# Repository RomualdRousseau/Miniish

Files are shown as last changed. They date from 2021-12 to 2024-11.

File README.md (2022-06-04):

# Miniish - Homebrew 6502 Computer

The goal of this project is to build a 8bit game console based on 6502 CPU.
The entire project is strongly inspired by the work and videos of Ben Eater, but
also Javidx9 and his emulator.

## Mother Board

It is basically the same hardware design presented by Ben Eater. I just cleaned
up the adress control logic to have as mush of the 32K RAM available.

The address plan is:

0000 --------------------------------

//   RAM

8000 --------------------------------

//   LO ROM

D000 --------------------------------

//   IRQ Status

D100 --------------------------------

//   PICTURE PROCESSING UNIT (PORT1B)

D200 --------------------------------

//   AUDIO PROCESSING UNIT (PORT2B)

D300 --------------------------------

//   I/O

D400 --------------------------------

//   Reserved

E000 --------------------------------

//   HI ROM

FFFF --------------------------------

## Picture Processing Unit (PPU)

### VGA Card

The card is built using a FPGA and strongly inspired to the NES PPU and the
capability of PICO-8.

The overall specs of the VGA card is 16 colors with a 128x128 display area using
the VGA 640x480 60Hz standard. The 16 colors are the PICO8 palette.

The VGA card is interfaced to the motherboard through a sprite based unit. The
video ram is not mapped to the computer ram but instead, the CPU sends instructions
to a sprite generator very similar to the NES (greatly based on Javidx9
explanations).

The overall spec of the sprite generator is:

* 1 nametables for the background composed of 16 * 16 tiles. Each tile is 8x8
pixels. Scrolling vertical and horizontal modes are supported.

* 256 sprites with tansparency support. Each sprite is also a tile of 8x8 pixels.

* 64 simultaneous sprites on screen and 16 sprites per scanline

* NMI is generated at each vertical blank

## Audio Procesing Unit (APU)

The card is built using a ATMEGA328p at 20Mhz with the library the_synth of Edgar.

The synthetizer has the overall spec: 

* 4 channels at 20KHz

* 4 waveforms: triangle, square, sinus + noise

* 4 envelopes

* modulation

* IRQ0 is generated as the next data frame callback

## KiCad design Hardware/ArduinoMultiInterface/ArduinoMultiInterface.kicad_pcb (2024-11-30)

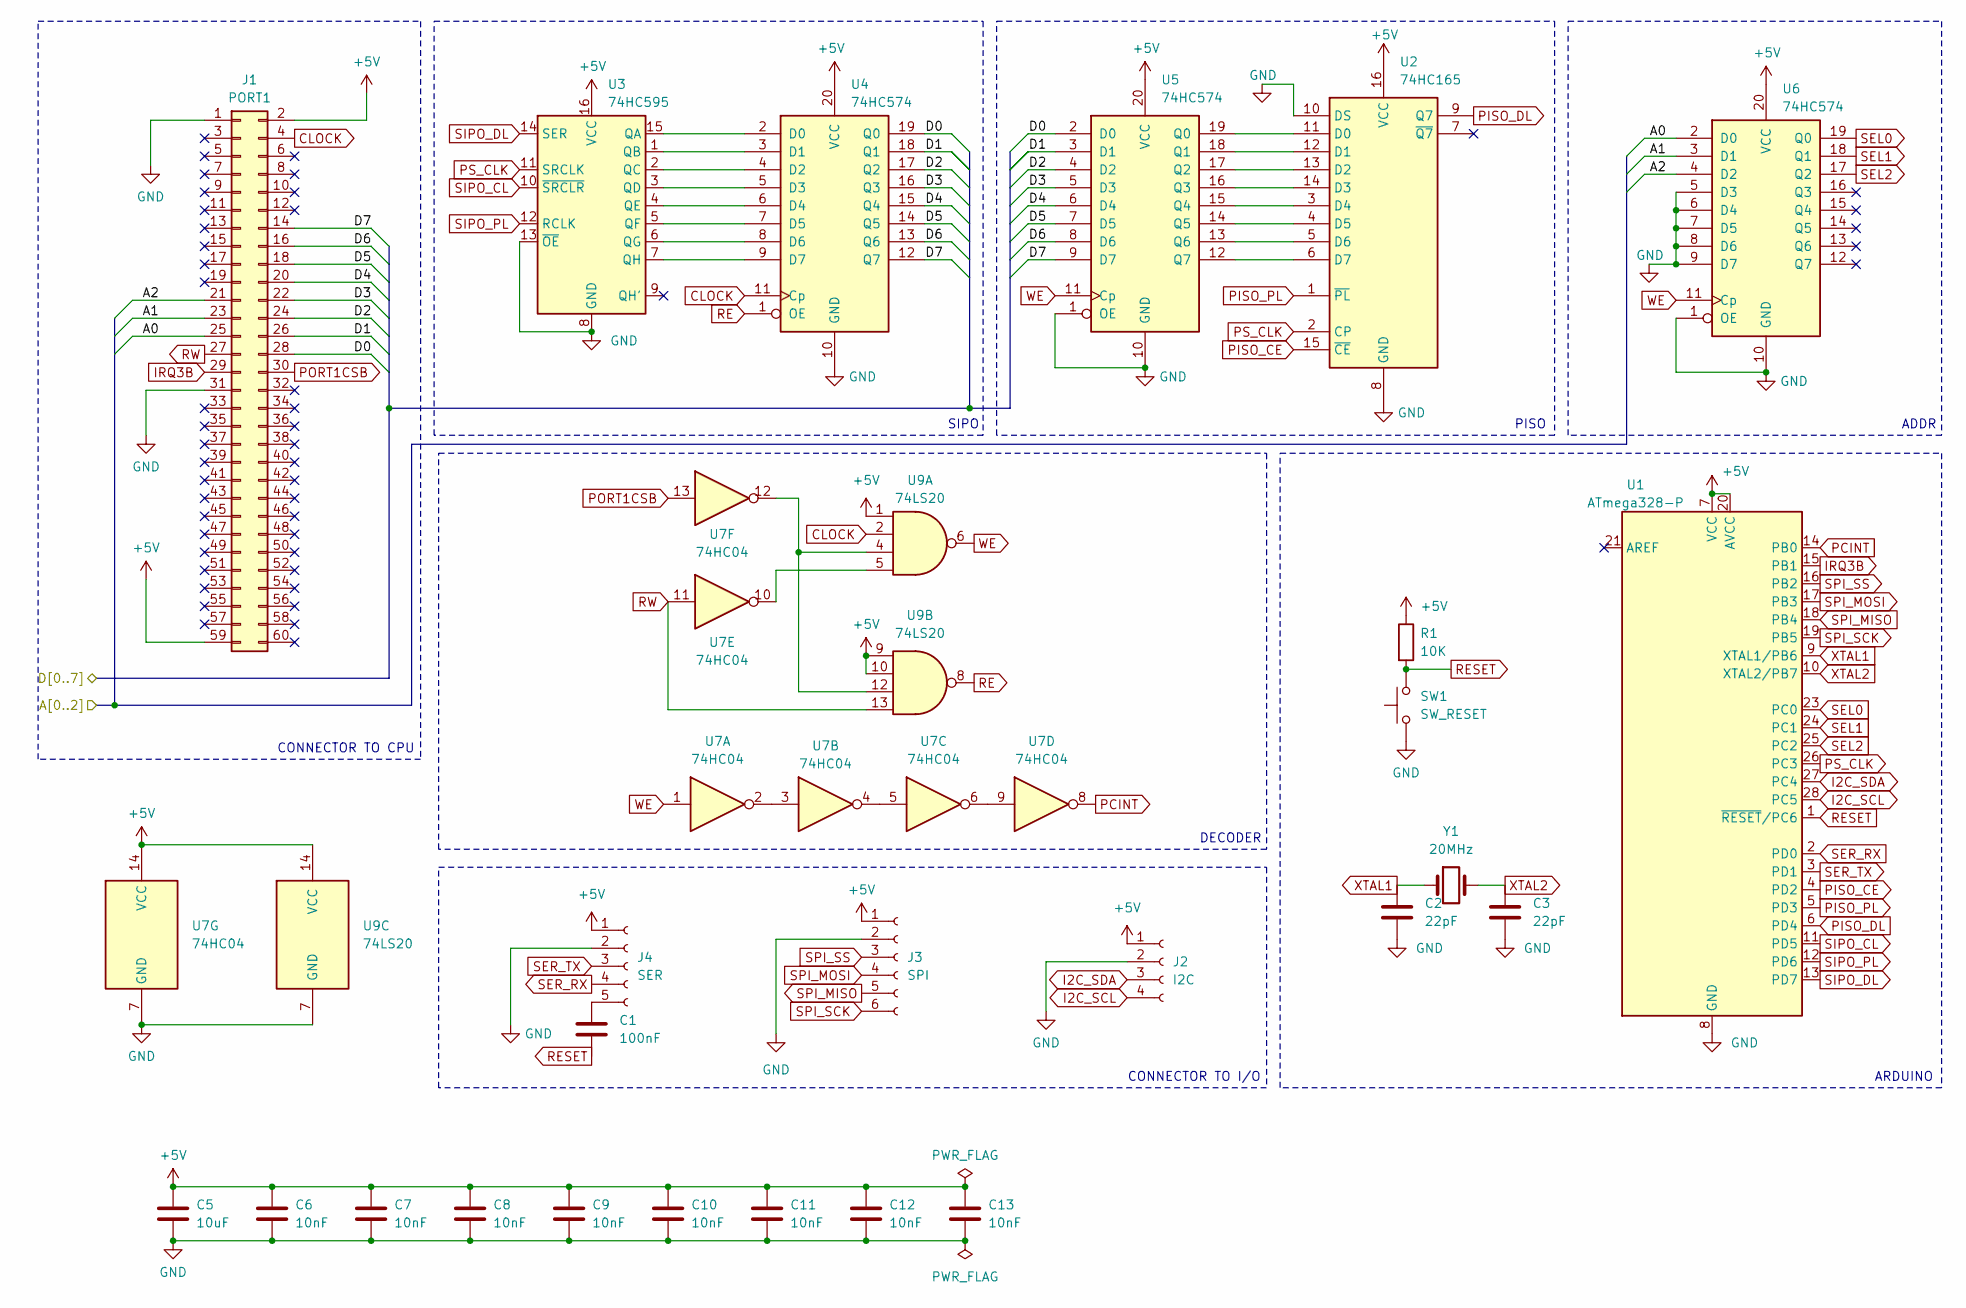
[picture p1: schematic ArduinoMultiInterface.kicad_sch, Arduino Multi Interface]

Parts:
C1: 100nF; C_Disc_D5.0mm_W2.5mm_P2.50mm
C2, C3: 22pF; C_Disc_D5.0mm_W2.5mm_P2.50mm
C5: 10uF; CP_Radial_D5.0mm_P2.00mm
C6, C7, C8, C9, C10, C11, C12, C13: 10nF; C_Disc_D5.0mm_W2.5mm_P5.00mm
J1: PORT1; NES_PCBEdge
J2: I2C; PinSocket_1x04_P2.54mm_Vertical
J3: SPI; PinSocket_1x06_P2.54mm_Vertical
J4: SER; PinSocket_1x05_P2.54mm_Vertical
R1: 10K; R_Axial_DIN0207_L6.3mm_D2.5mm_P10.16mm_Horizontal
SW1: SW_RESET; SW_PUSH_6mm
U1: ATmega328-P; DIP-28_W7.62mm
U2: 74HC165; DIP-16_W7.62mm
U3: 74HC595; DIP-16_W7.62mm
U4, U5, U6: 74HC574; DIP-20_W7.62mm
U7: 74HC04; DIP-14_W7.62mm
U9: 74LS20; DIP-14_W7.62mm
Y1: 20MHz; Crystal_HC49-4H_Vertical

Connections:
+5V: C5.1, C6.1, C7.1, C8.1, C9.1, C10.1, C11.1, C12.1, C13.1, J1.2, J1.59, J2.1, J3.1, J4.1, R1.1, U1.7 (VCC), U1.20 (AVCC), U2.16 (VCC), U3.16 (VCC), U4.20 (VCC), U5.20 (VCC), U6.20 (VCC), U7.14 (VCC), U9.1, U9.9, U9.10, U9.14 (VCC)
/A0: J1.25, U6.2 (D0)
/A1: J1.23, U6.3 (D1)
/A2: J1.21, U6.4 (D2)
/D0: J1.28, U4.19 (Q0), U5.2 (D0)
/D1: J1.26, U4.18 (Q1), U5.3 (D1)
/D2: J1.24, U4.17 (Q2), U5.4 (D2)
/D3: J1.22, U4.16 (Q3), U5.5 (D3)
/D4: J1.20, U4.15 (Q4), U5.6 (D4)
/D5: J1.18, U4.14 (Q5), U5.7 (D5)
/D6: J1.16, U4.13 (Q6), U5.8 (D6)
/D7: J1.14, U4.12 (Q7), U5.9 (D7)
CLOCK: J1.4, U4.11 (Cp), U9.2
GND: C2.2, C3.2, C5.2, C6.2, C7.2, C8.2, C9.2, C10.2, C11.2, C12.2, C13.2, J1.1, J1.31, J2.2, J3.2, J4.2, SW1.1, U1.8 (GND), U1.22 (GND), U2.8 (GND), U2.10 (DS), U3.8 (GND), U3.13 (~OE), U4.10 (GND), U5.1 (OE), U5.10 (GND), U6.1 (OE), U6.5 (D3), U6.6 (D4), U6.7 (D5), U6.8 (D6), U6.9 (D7), U6.10 (GND), U7.7 (GND), U9.7 (GND)
I2C_SCL: J2.4, U1.28 (PC5)
I2C_SDA: J2.3, U1.27 (PC4)
IRQ3B: J1.29, U1.15 (PB1)
unnamed: C1.1, J4.5
unnamed: U2.11 (D0), U5.19 (Q0)
unnamed: U2.12 (D1), U5.18 (Q1)
unnamed: U2.13 (D2), U5.17 (Q2)
unnamed: U2.14 (D3), U5.16 (Q3)
unnamed: U2.3 (D4), U5.15 (Q4)
unnamed: U2.4 (D5), U5.14 (Q5)
unnamed: U2.5 (D6), U5.13 (Q6)
unnamed: U2.6 (D7), U5.12 (Q7)
unnamed: U3.15 (QA), U4.2 (D0)
unnamed: U3.1 (QB), U4.3 (D1)
unnamed: U3.2 (QC), U4.4 (D2)
unnamed: U3.3 (QD), U4.5 (D3)
unnamed: U3.4 (QE), U4.6 (D4)
unnamed: U3.5 (QF), U4.7 (D5)
unnamed: U3.6 (QG), U4.8 (D6)
unnamed: U3.7 (QH), U4.9 (D7)
unnamed: U7.2, U7.3
unnamed: U7.4, U7.5
unnamed: U7.6, U7.9
unnamed: U7.10, U9.5
unnamed: U7.12, U9.4, U9.12
PCINT: U1.14 (PB0), U7.8
PISO_CE: U1.4 (PD2), U2.15 (~CE)
PISO_DL: U1.6 (PD4), U2.9 (Q7)
PISO_PL: U1.5 (PD3), U2.1 (~PL)
PORT1CSB: J1.30, U7.13
PS_CLK: U1.26 (PC3), U2.2 (CP), U3.11 (SRCLK)
RE: U4.1 (OE), U9.8
RESET: C1.2, R1.2, SW1.2, U1.1 (~RESET/PC6)
RW: J1.27, U7.11, U9.13
SEL0: U1.23 (PC0), U6.19 (Q0)
SEL1: U1.24 (PC1), U6.18 (Q1)
SEL2: U1.25 (PC2), U6.17 (Q2)
SER_RX: J4.4, U1.2 (PD0)
SER_TX: J4.3, U1.3 (PD1)
SIPO_CL: U1.11 (PD5), U3.10 (~SRCLR)
SIPO_DL: U1.13 (PD7), U3.14 (SER)
SIPO_PL: U1.12 (PD6), U3.12 (RCLK)
SPI_MISO: J3.5, U1.18 (PB4)
SPI_MOSI: J3.4, U1.17 (PB3)
SPI_SCK: J3.6, U1.19 (PB5)
SPI_SS: J3.3, U1.16 (PB2)
WE: U5.11 (Cp), U6.11 (Cp), U7.1, U9.6
XTAL1: C2.1, U1.9 (XTAL1/PB6), Y1.1
XTAL2: C3.1, U1.10 (XTAL2/PB7), Y1.2

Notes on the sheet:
CONNECTOR TO CPU
ARDUINO
PISO
DECODER
SIPO
ADDR
CONNECTOR TO I/O

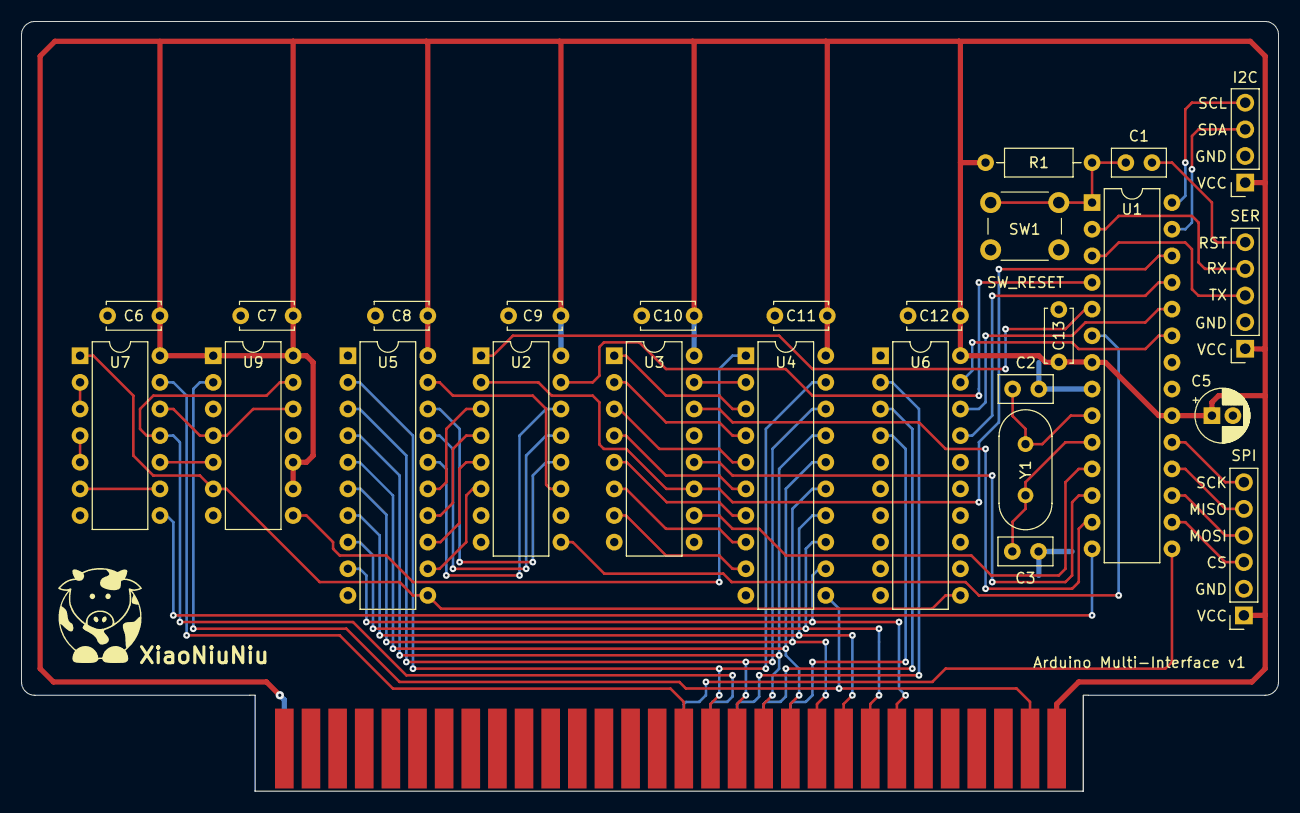
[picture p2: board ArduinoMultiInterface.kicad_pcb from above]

Board: 2 copper layers, 119.9 x 73.4 mm, 28 parts (0 on the bottom side), 63 nets.

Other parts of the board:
XiaoNiuNiu: LOGO; VerySmallCow

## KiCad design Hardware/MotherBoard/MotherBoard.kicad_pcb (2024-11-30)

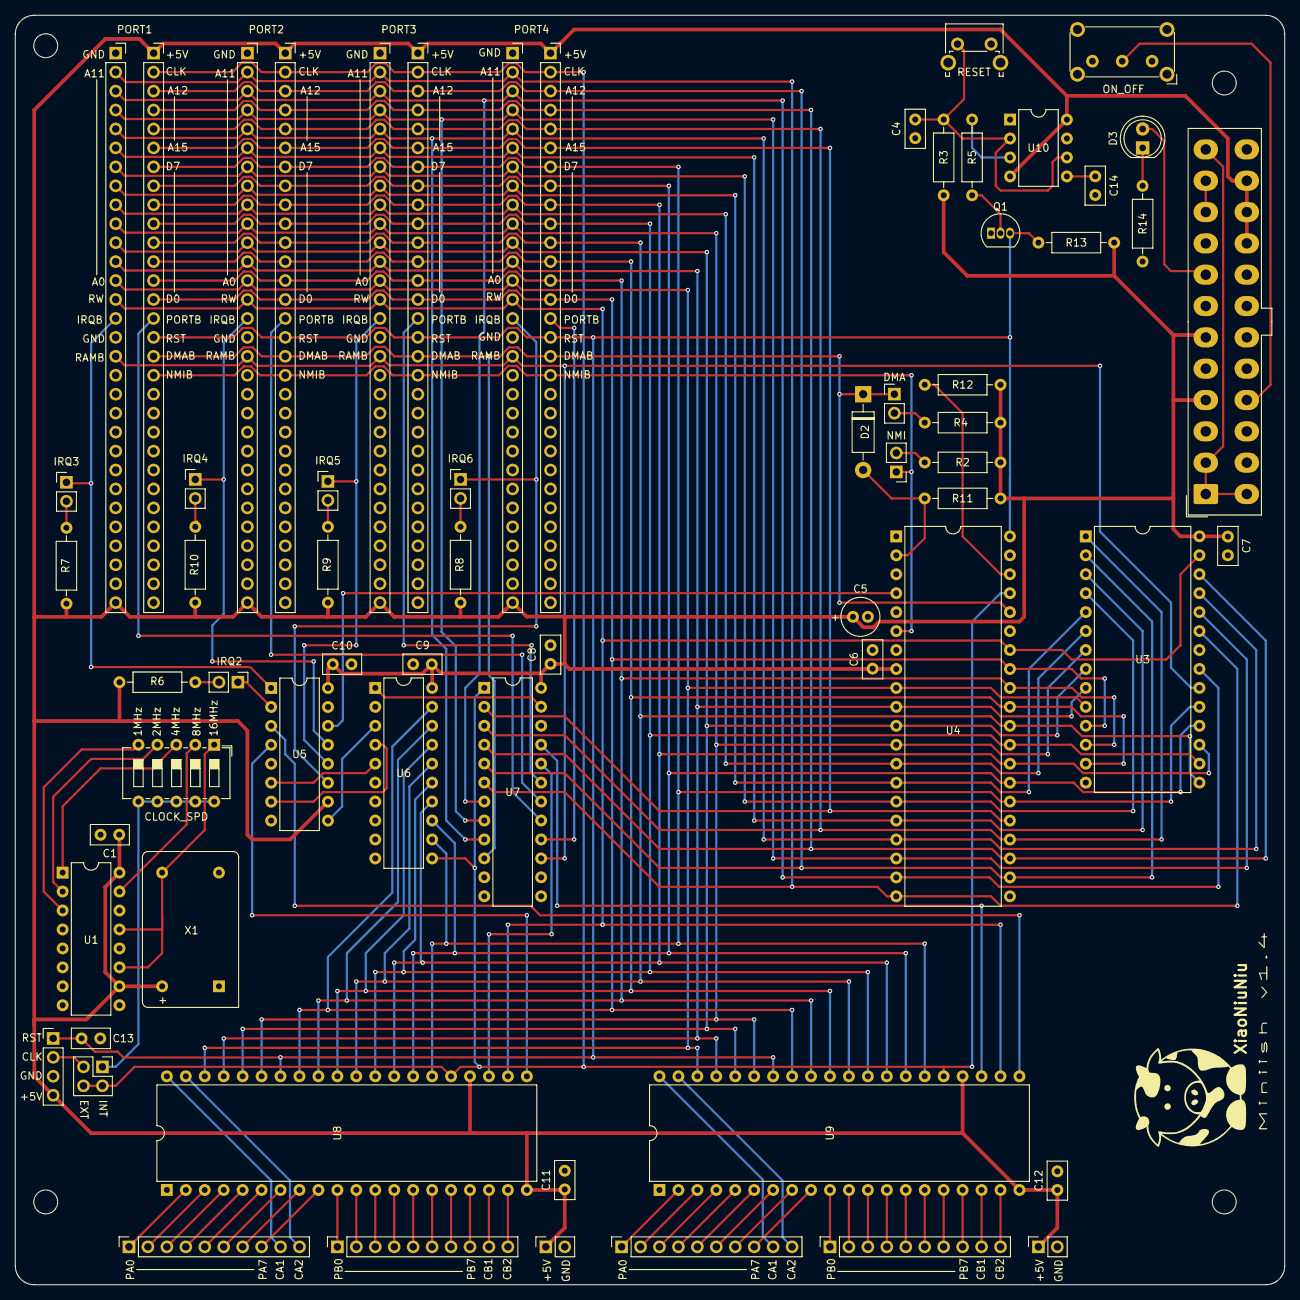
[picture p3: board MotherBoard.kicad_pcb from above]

Board: 2 copper layers, 170.2 x 170.2 mm, 66 parts (0 on the bottom side), 113 nets.

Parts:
C1, C4, C6, C7, C9, C10, C11, C12, C13: 100nF; C_Disc_D5.0mm_W2.5mm_P2.50mm
C5: 10uF; C_Radial_D5.0mm_H11.0mm_P2.00mm
C8: 220nF; C_Disc_D5.0mm_W2.5mm_P2.50mm
C14: 10nF; C_Disc_D5.0mm_W2.5mm_P2.50mm
D2: 1N4001; D_DO-41_SOD81_P10.16mm_Horizontal
D3: LED; LED_D5.0mm
H1, H2, H3, H4: MountingHole_Pad; MountingHole_3.2mm_M3
J3: CLOCK_SEL; PinHeader_2x02_P2.54mm_Vertical
J4: EXTRN_CLCK; PinHeader_1x04_P2.54mm_Vertical
J5: NMI; PinHeader_1x02_P2.54mm_Vertical
J6: DMA; PinHeader_1x02_P2.54mm_Vertical
J7: IRQ2; PinHeader_1x02_P2.54mm_Vertical
J8: IRQ3; PinHeader_1x02_P2.54mm_Vertical
J9: IRQ6; PinHeader_1x02_P2.54mm_Vertical
J10: IRQ5; PinHeader_1x02_P2.54mm_Vertical
J11: IRQ4; PinHeader_1x02_P2.54mm_Vertical
J14: PORT1; NES_Cartdrige
J16: PORT2; NES_Cartdrige
J17: PORT3; NES_Cartdrige
J18: PORT4/ROM; NES_Cartdrige
J19: GPIO1; PinSocket_1x10_P2.54mm_Vertical
J20: GPIO2; PinSocket_1x10_P2.54mm_Vertical
J21: GPIO1_PWR; PinSocket_1x02_P2.54mm_Vertical
J22: GPIO3; PinSocket_1x10_P2.54mm_Vertical
J23: GPIO4; PinSocket_1x10_P2.54mm_Vertical
J24: GPIO2_PWR; PinSocket_1x02_P2.54mm_Vertical
J25: ATX-24; Molex_Mini-Fit_Jr_5566-24A_2x12_P4.20mm_Vertical
Q1: 2N3904; TO-92_Inline
R2, R4, R6, R7, R8, R9, R10, R11, R12: 3K3; R_Axial_DIN0207_L6.3mm_D2.5mm_P10.16mm_Horizontal
R3: 1M; R_Axial_DIN0207_L6.3mm_D2.5mm_P10.16mm_Horizontal
R5: 4.7K; R_Axial_DIN0207_L6.3mm_D2.5mm_P10.16mm_Horizontal
R13: 10K; R_Axial_DIN0207_L6.3mm_D2.5mm_P10.16mm_Horizontal
R14: 220; R_Axial_DIN0207_L6.3mm_D2.5mm_P10.16mm_Horizontal
SW1: CLOCK_SPD; SW_DIP_SPSTx05_Slide_6.7x14.26mm_W7.62mm_P2.54mm_LowProfile
SW2: ON_OFF; SW_E-Switch_EG1224_SPDT_Angled
SW3: RESET; SW_Tactile_SPST_Angled_PTS645Vx83-2LFS
U1: 74HC590A; DIP-16_W7.62mm
U3: AS6C62256; DIP-28_W15.24mm
U4: WD65C02; DIP-40_W15.24mm
U5: 74HC148; DIP-16_W7.62mm
U6: 74HC574; DIP-20_W7.62mm
U7: ATF22V10B; DIP-24_W7.62mm
U8, U9: WD65C22; DIP-40_W15.24mm
U10: NE555P; DIP-8_W7.62mm
X1: ACO-16MHz; Oscillator_DIP-14
XiaoNiuNiu: LOGO; SmallCow

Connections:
+5V: C1.1, C5.1, C6.1, C7.1, C8.1, C9.1, C10.1, C11.1, C12.1, J4.4, J14.2, J14.59, J16.2, J16.59, J17.2, J17.59, J18.2, J18.59, J21.1, J24.1, J25.4 (+5V), J25.6 (+5V), J25.21 (+5V), J25.22 (+5V), J25.23 (+5V), R2.2, R3.1, R4.2, R6.2, R7.2, R8.2, R9.2, R10.2, R11.2, R12.2, R13.2, U1.10 (~MRC), U1.16 (VCC), U3.28 (VCC), U4.8 (VCC), U5.10 (IO), U5.16 (VCC), U6.20 (VCC), U7.24 (VCC), U8.20 (VCC), U8.24 (CS1), U9.20 (VCC), U9.24 (CS1), U10.4 (R), U10.8 (VCC), X1.14 (Vcc)
/1MHz: SW1.5, U1.3 (Q3)
/2MHz: SW1.4, U1.2 (Q2)
/4MHz: SW1.3, U1.1 (Q1)
/8MHz: SW1.2, U1.15 (Q0)
/16MHz: SW1.1, U1.11 (CPC), U1.13 (CPR), X1.8 (OUT)
/GPIO/A0: J14.25, J16.25, J17.25, J18.25, U3.10 (A0), U4.9 (A0), U8.38 (RS0), U9.38 (RS0)
/GPIO/A1: J14.23, J16.23, J17.23, J18.23, U3.9 (A1), U4.10 (A1), U8.37 (RS1), U9.37 (RS1)
/GPIO/A2: J14.21, J16.21, J17.21, J18.21, U3.8 (A2), U4.11 (A2), U8.36 (RS2), U9.36 (RS2)
/GPIO/A3: J14.19, J16.19, J17.19, J18.19, U3.7 (A3), U4.12 (A3), U8.35 (RS3), U9.35 (RS3)
/GPIO/A4: J14.17, J16.17, J17.17, J18.17, U3.6 (A4), U4.13 (A4)
/GPIO/A5: J14.15, J16.15, J17.15, J18.15, U3.5 (A5), U4.14 (A5)
/GPIO/A6: J14.13, J16.13, J17.13, J18.13, U3.4 (A6), U4.15 (A6)
/GPIO/A7: J14.11, J16.11, J17.11, J18.11, U3.3 (A7), U4.16 (A7)
/GPIO/A8: J14.9, J16.9, J17.9, J18.9, U3.25 (A8), U4.17 (A8), U7.9 (I7)
/GPIO/A9: J14.7, J16.7, J17.7, J18.7, U3.24 (A9), U4.18 (A9), U7.8 (I6)
/GPIO/A10: J14.5, J16.5, J17.5, J18.5, U3.21 (A10), U4.19 (A10), U7.7 (I5)
/GPIO/A11: J14.3, J16.3, J17.3, J18.3, U3.23 (A11), U4.20 (A11), U7.6 (I4)
/GPIO/A12: J14.6, J16.6, J17.6, J18.6, U3.2 (A12), U4.22 (A12), U7.5 (I3)
/GPIO/A13: J14.8, J16.8, J17.8, J18.8, U3.26 (A13), U4.23 (A13), U7.4 (I2)
/GPIO/A14: J14.10, J16.10, J17.10, J18.10, U3.1 (A14), U4.24 (A14), U7.3 (I1)
/GPIO/A15: J14.12, J16.12, J17.12, J18.12, U4.25 (A15), U7.2 (I0)
/GPIO/CIA1CSB: U7.20 (O3), U8.23 (~CS2)
/GPIO/CIA2CSB: U7.21 (O2), U9.23 (~CS2)
/GPIO/D0: J14.28, J16.28, J17.28, J18.28, U3.11 (Q0), U4.33 (D0), U6.19 (Q0), U8.33 (D0), U9.33 (D0)
/GPIO/D1: J14.26, J16.26, J17.26, J18.26, U3.12 (Q1), U4.32 (D1), U6.18 (Q1), U8.32 (D1), U9.32 (D1)
/GPIO/D2: J14.24, J16.24, J17.24, J18.24, U3.13 (Q2), U4.31 (D2), U6.17 (Q2), U8.31 (D2), U9.31 (D2)
/GPIO/D3: J14.22, J16.22, J17.22, J18.22, U3.15 (Q3), U4.30 (D3), U6.16 (Q3), U8.30 (D3), U9.30 (D3)
/GPIO/D4: J14.20, J16.20, J17.20, J18.20, U3.16 (Q4), U4.29 (D4), U6.15 (Q4), U8.29 (D4), U9.29 (D4)
/GPIO/D5: J14.18, J16.18, J17.18, J18.18, U3.17 (Q5), U4.28 (D5), U6.14 (Q5), U8.28 (D5), U9.28 (D5)
/GPIO/D6: J14.16, J16.16, J17.16, J18.16, U3.18 (Q6), U4.27 (D6), U6.13 (Q6), U8.27 (D6), U9.27 (D6)
/GPIO/D7: J14.14, J16.14, J17.14, J18.14, U3.19 (Q7), U4.26 (D7), U6.12 (Q7), U8.26 (D7), U9.26 (D7)
/GPIO/IRQ0B: U5.4 (I7), U8.21 (~IRQ)
/GPIO/IRQ1B: U5.3 (I6), U9.21 (~IRQ)
/GPIO/RW: J14.27, J16.27, J17.27, J18.27, U3.27 (~WE), U4.34 (R/~W), U8.22 (R/~W), U9.22 (R/~W)
/North Bridge/DMAB: D2.1 (K), J6.1, J14.34, J16.34, J17.34, J18.34, U4.36 (BE), U7.10 (I8)
/North Bridge/IRQB: U4.4 (~IRQ), U5.14 (GS)
/North Bridge/NMIB: J5.1, J14.36, J16.36, J17.36, J18.36, U4.6 (~NMI)
/North Bridge/RAMCSB: J14.33, J16.33, J17.33, J18.33, U3.20 (~CS), U7.15 (O8)
/North Bridge/RDY: D2.2 (A), R11.1, U4.2 (RDY)
/North Bridge/SOB: R12.1, U4.38 (~SO)
/Ports/IRQ2B: J7.1, U5.2 (I5)
/Ports/IRQ3B: J8.1, J14.29, U5.1 (I4)
/Ports/IRQ4B: J11.1, J16.29, U5.13 (I3)
/Ports/IRQ5B: J10.1, J17.29, U5.12 (I2)
/Ports/IRQ6B: J9.1, J18.29, U5.11 (I1)
/Ports/PORT1CSB: J14.30, U7.17 (O6)
/Ports/PORT2CSB: J16.30, U7.18 (O5)
/Ports/PORT3CSB: J17.30, U7.19 (O4)
/Ports/ROMCSB: J18.30, U7.16 (O7)
CA11: J19.9, U8.40 (CA1)
CA12: J19.10, U8.39 (CA2)
CA21: J22.9, U9.40 (CA1)
CA22: J22.10, U9.39 (CA2)
CB11: J20.9, U8.18 (CB1)
CB12: J20.10, U8.19 (CB2)
CB21: J23.9, U9.18 (CB1)
CB22: J23.10, U9.19 (CB2)
CLOCK: J3.2, J3.4, J14.4, J16.4, J17.4, J18.4, U4.37 (PHI2), U6.11 (Cp), U7.1 (CLK), U8.25 (PHI2), U9.25 (PHI2)
ECLOCK: J3.3, J4.2
GND: C1.2, C4.2, C5.2, C6.2, C7.2, C8.2, C9.2, C10.2, C11.2, C12.2, C13.2, C14.2, J4.3, J14.1, J14.31, J16.1, J16.31, J17.1, J17.31, J18.1, J18.31, J21.2, J24.2, J25.3 (GND), J25.5 (GND), J25.7 (GND), J25.15 (GND), J25.17 (GND), J25.18 (GND), J25.19 (GND), J25.24 (GND), Q1.1 (E), R14.2, SW2.1 (A), SW3.2, U1.8 (GND), U1.12 (~CE), U1.14 (~OE), U3.14 (GND), U3.22 (~OE), U4.21 (GND), U5.5 (EI), U5.8 (GND), U6.2 (D0), U6.6 (D4), U6.7 (D5), U6.8 (D6), U6.9 (D7), U6.10 (GND), U7.11 (I9), U7.12 (GND), U7.13 (~OE), U8.1 (GND), U9.1 (GND), U10.1 (GND), X1.7 (GND)
unnamed: D3.1 (K), R14.1
unnamed: J3.1, SW1.6, SW1.7, SW1.8, SW1.9, SW1.10
unnamed: J5.2, R2.1
unnamed: J6.2, R4.1
unnamed: J7.2, R6.1
unnamed: J8.2, R7.1
unnamed: J9.2, R8.1
unnamed: J10.2, R9.1
unnamed: J11.2, R10.1
unnamed: J25.16 (PS_ON#), SW2.2 (B)
unnamed: Q1.2 (B), R5.2
unnamed: U5.9 (S0), U6.3 (D1)
unnamed: U5.7 (S1), U6.4 (D2)
unnamed: U5.6 (S2), U6.5 (D3)
unnamed: U6.1 (OE), U7.23 (O0)
unnamed: C14.1, U10.5 (CV)
unnamed: R5.1, U10.3 (Q)
unnamed: C4.1, R3.2, SW3.1, U10.2 (TR), U10.6 (THR)
PA10: J19.1, U8.2 (PA0)
PA11: J19.2, U8.3 (PA1)
PA12: J19.3, U8.4 (PA2)
PA13: J19.4, U8.5 (PA3)
PA14: J19.5, U8.6 (PA4)
PA15: J19.6, U8.7 (PA5)
PA16: J19.7, U8.8 (PA6)
PA17: J19.8, U8.9 (PA7)
PA20: J22.1, U9.2 (PA0)
PA21: J22.2, U9.3 (PA1)
PA22: J22.3, U9.4 (PA2)
PA23: J22.4, U9.5 (PA3)
PA24: J22.5, U9.6 (PA4)
PA25: J22.6, U9.7 (PA5)
PA26: J22.7, U9.8 (PA6)
PA27: J22.8, U9.9 (PA7)
PB10: J20.1, U8.10 (PB0)
PB11: J20.2, U8.11 (PB1)
PB12: J20.3, U8.12 (PB2)
PB13: J20.4, U8.13 (PB3)
PB14: J20.5, U8.14 (PB4)
PB15: J20.6, U8.15 (PB5)
PB16: J20.7, U8.16 (PB6)
PB17: J20.8, U8.17 (PB7)
PB20: J23.1, U9.10 (PB0)
PB21: J23.2, U9.11 (PB1)
PB22: J23.3, U9.12 (PB2)
PB23: J23.4, U9.13 (PB3)
PB24: J23.5, U9.14 (PB4)
PB25: J23.6, U9.15 (PB5)
PB26: J23.7, U9.16 (PB6)
PB27: J23.8, U9.17 (PB7)
PWR_OK: D3.2 (A), J25.8 (PWR_OK)
RESET: C13.1, J4.1, J14.32, J16.32, J17.32, J18.32, Q1.3 (C), R13.1, U4.40 (~RESET), U8.34 (~RESET), U9.34 (~RESET)

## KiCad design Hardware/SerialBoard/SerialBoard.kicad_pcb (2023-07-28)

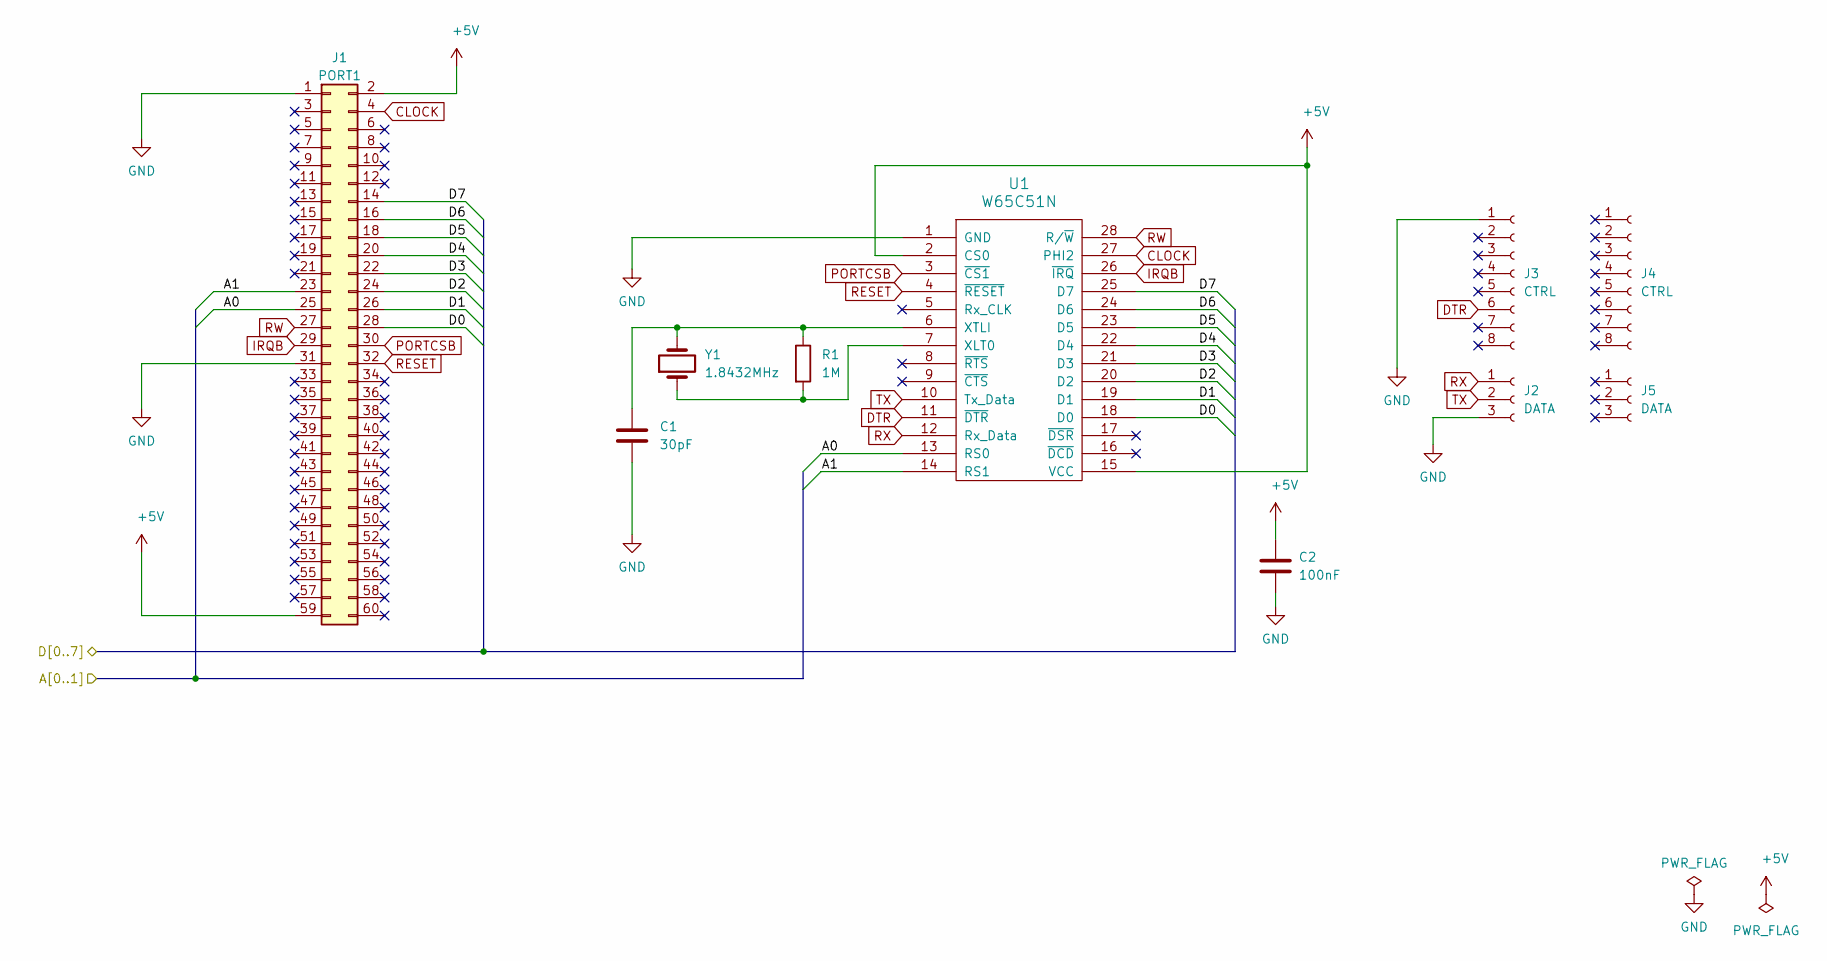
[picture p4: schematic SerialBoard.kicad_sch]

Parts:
C1: 30pF; C_Disc_D5.0mm_W2.5mm_P2.50mm
C2: 100nF; C_Disc_D5.0mm_W2.5mm_P2.50mm
J1: PORT1; NES_PCBEdge
J2, J5: DATA; PinSocket_1x03_P2.54mm_Vertical
J3, J4: CTRL; PinSocket_1x08_P2.54mm_Vertical
R1: 1M; R_Axial_DIN0207_L6.3mm_D2.5mm_P10.16mm_Horizontal
U1: W65C51N; DIP-28_W15.24mm
Y1: 1.8432MHz; Crystal_HC49-4H_Vertical

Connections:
+5V: C2.1, J1.2, J1.59, U1.2 (CS0), U1.15 (VCC)
/A0: J1.25, U1.13 (RS0)
/A1: J1.23, U1.14 (RS1)
/D0: J1.28, U1.18 (D0)
/D1: J1.26, U1.19 (D1)
/D2: J1.24, U1.20 (D2)
/D3: J1.22, U1.21 (D3)
/D4: J1.20, U1.22 (D4)
/D5: J1.18, U1.23 (D5)
/D6: J1.16, U1.24 (D6)
/D7: J1.14, U1.25 (D7)
CLOCK: J1.4, U1.27 (PHI2)
DTR: J3.6, U1.11 (~DTR)
GND: C1.2, C2.2, J1.1, J1.31, J2.3, J3.1, U1.1 (GND)
IRQB: J1.29, U1.26 (~IRQ)
unnamed: R1.2, U1.7 (XLT0), Y1.1
unnamed: C1.1, R1.1, U1.6 (XTLI), Y1.2
PORTCSB: J1.30, U1.3 (~CS1)
RESET: J1.32, U1.4 (~RESET)
RW: J1.27, U1.28 (R/~W)
RX: J2.1, U1.12 (Rx_Data)
TX: J2.2, U1.10 (Tx_Data)

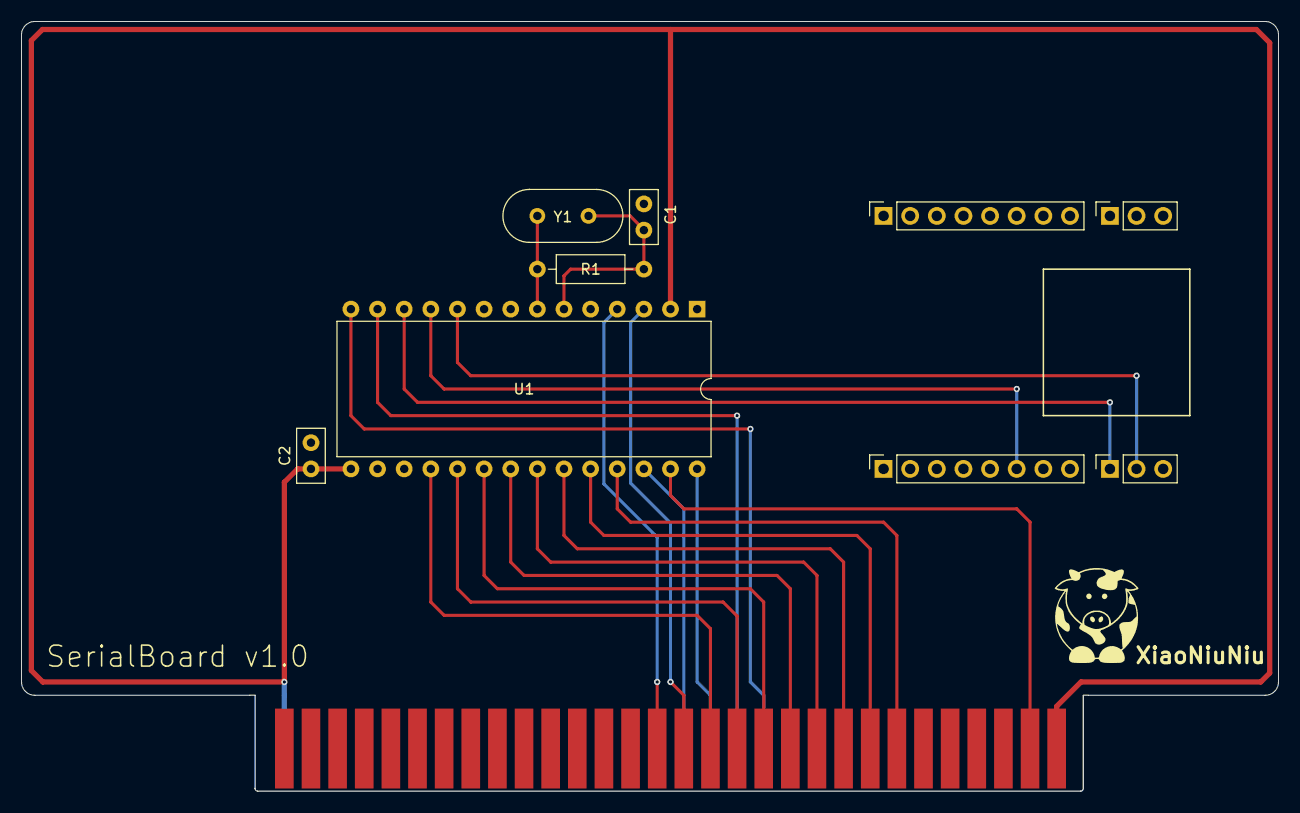
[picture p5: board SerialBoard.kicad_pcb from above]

Board: 2 copper layers, 119.9 x 73.4 mm, 11 parts (0 on the bottom side), 22 nets.

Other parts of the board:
XiaoNiuNiu: LOGO; VerySmallCow

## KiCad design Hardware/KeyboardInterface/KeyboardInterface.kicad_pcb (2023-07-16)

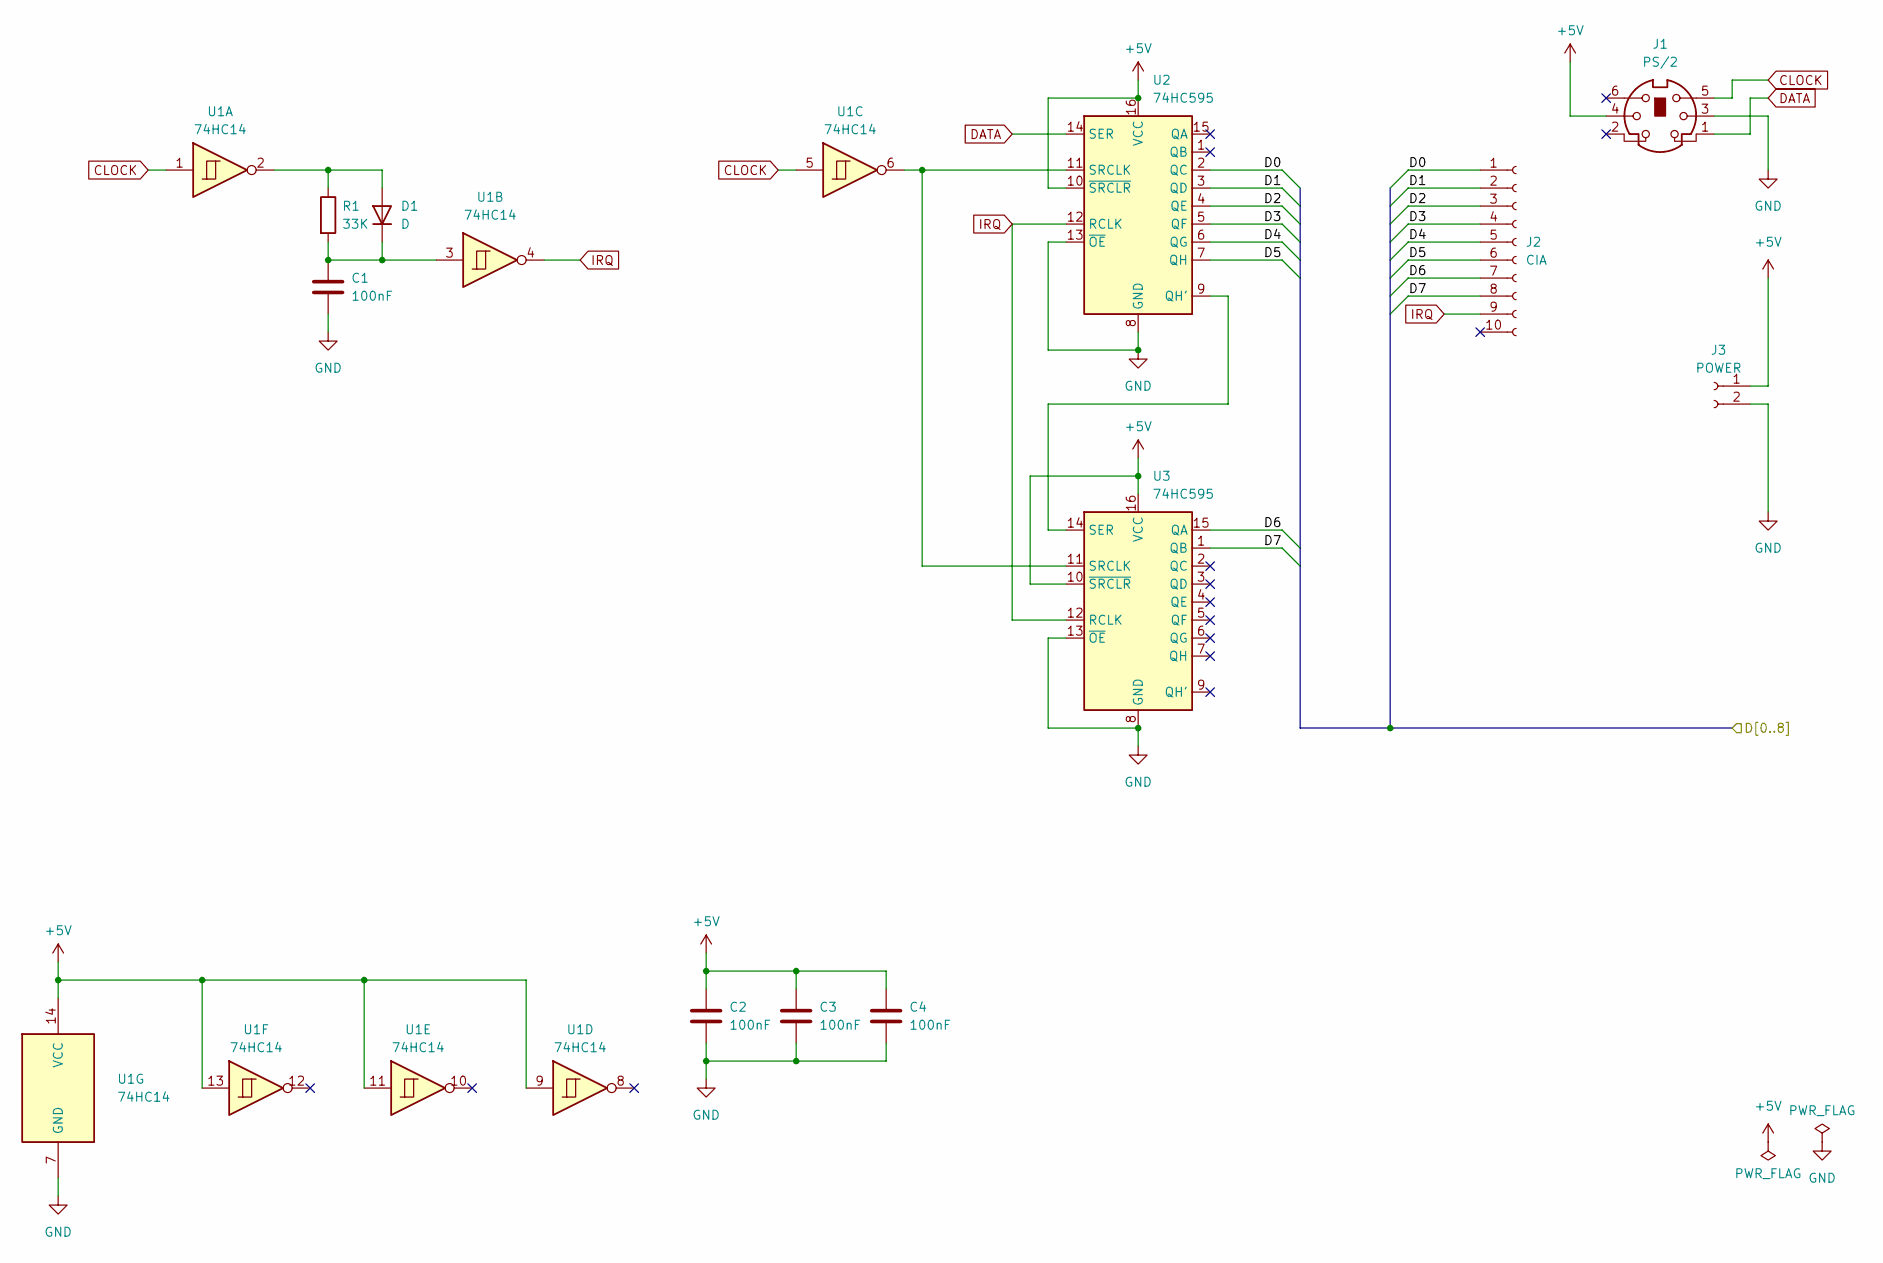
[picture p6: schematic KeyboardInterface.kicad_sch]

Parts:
C1, C2, C3, C4: 100nF; C_Disc_D5.0mm_W2.5mm_P2.50mm
D1: D; D_A-405_P10.16mm_Horizontal
J1: PS/2; Mini_din6
J2: CIA; PinSocket_1x10_P2.54mm_Vertical
J3: POWER; PinSocket_1x02_P2.54mm_Vertical
R1: 33K; R_Axial_DIN0309_L9.0mm_D3.2mm_P12.70mm_Horizontal
U1: 74HC14; DIP-14_W7.62mm
U2, U3: 74HC595; DIP-16_W7.62mm

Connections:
+5V: C2.1, C3.1, C4.1, J1.4, J3.1, U1.9, U1.11, U1.13, U1.14 (VCC), U2.10 (~SRCLR), U2.16 (VCC), U3.10 (~SRCLR), U3.16 (VCC)
/D0: J2.1, U2.2 (QC)
/D1: J2.2, U2.3 (QD)
/D2: J2.3, U2.4 (QE)
/D3: J2.4, U2.5 (QF)
/D4: J2.5, U2.6 (QG)
/D5: J2.6, U2.7 (QH)
/D6: J2.7, U3.15 (QA)
/D7: J2.8, U3.1 (QB)
CLOCK: J1.5, U1.1, U1.5
DATA: J1.1, U2.14 (SER)
GND: C1.2, C2.2, C3.2, C4.2, J1.3, J3.2, U1.7 (GND), U2.8 (GND), U2.13 (~OE), U3.8 (GND), U3.13 (~OE)
IRQ: J2.9, U1.4, U2.12 (RCLK), U3.12 (RCLK)
unnamed: D1.2 (A), R1.1, U1.2
unnamed: C1.1, D1.1 (K), R1.2, U1.3
unnamed: U2.9 (QH'), U3.14 (SER)
unnamed: U1.6, U2.11 (SRCLK), U3.11 (SRCLK)

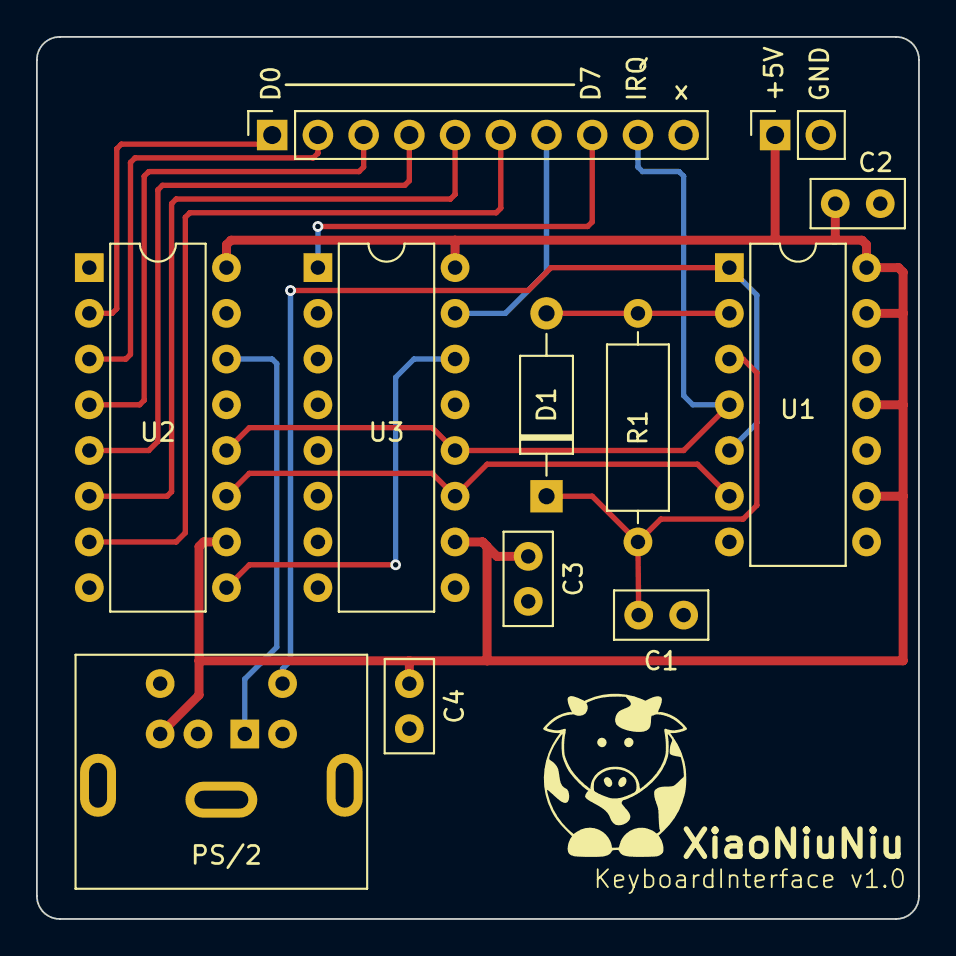
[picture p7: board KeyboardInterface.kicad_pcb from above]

Board: 2 copper layers, 49.0 x 49.0 mm, 13 parts (0 on the bottom side), 17 nets.

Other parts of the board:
XiaoNiuNiu: LOGO; VerySmallCow

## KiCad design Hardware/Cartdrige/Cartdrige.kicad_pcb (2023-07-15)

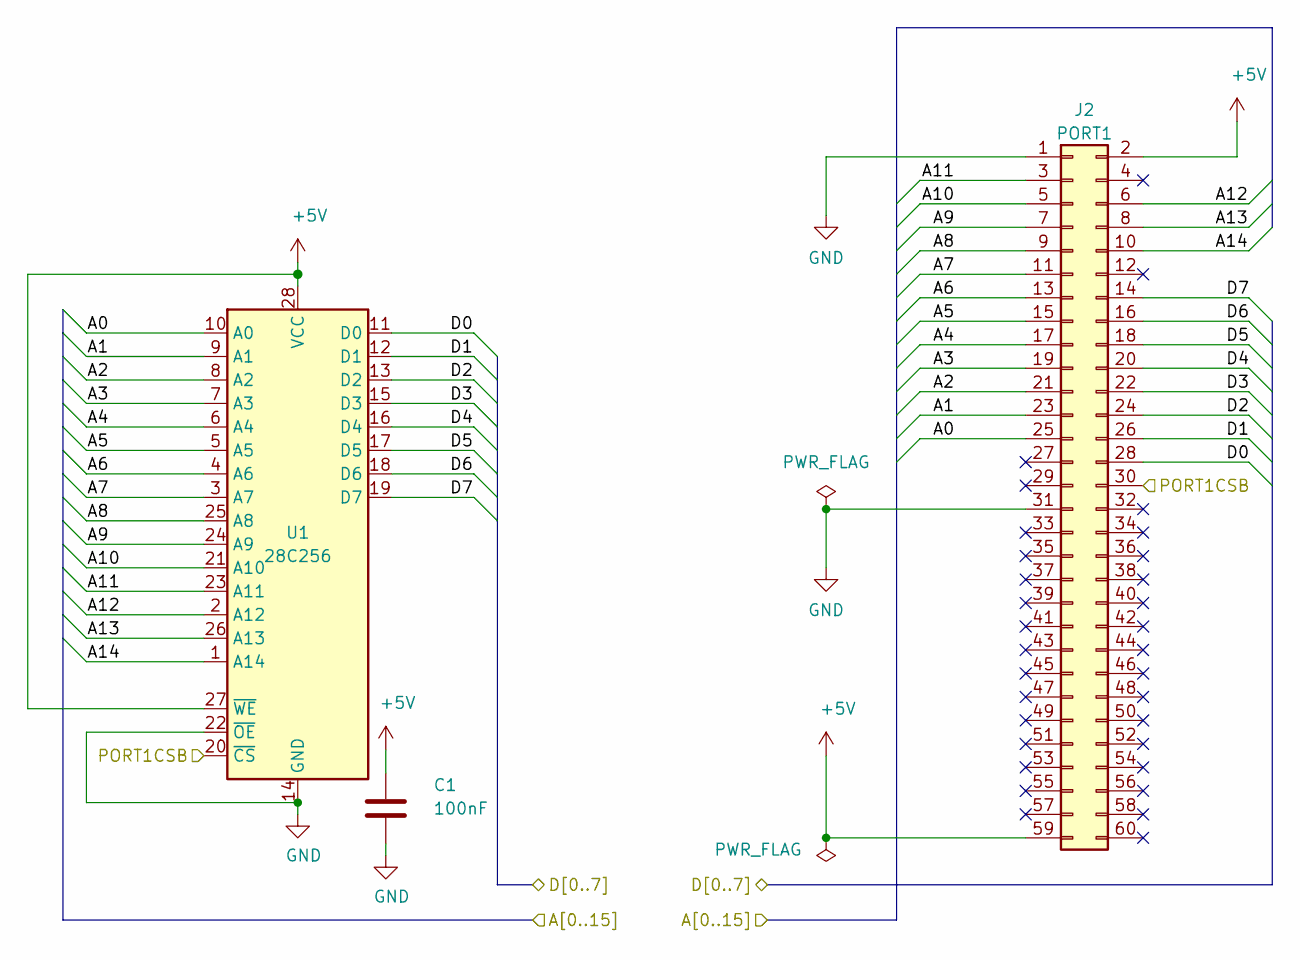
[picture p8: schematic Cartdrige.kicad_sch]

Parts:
C1: 100nF; C_Disc_D5.0mm_W2.5mm_P2.50mm
J2: PORT1; NES_PCBEdge
U1: 28C256; DIP-28_W15.24mm

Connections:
+5V: C1.1, J2.2, J2.59, U1.27 (~WE), U1.28 (VCC)
/A0: J2.25, U1.10 (A0)
/A1: J2.23, U1.9 (A1)
/A2: J2.21, U1.8 (A2)
/A3: J2.19, U1.7 (A3)
/A4: J2.17, U1.6 (A4)
/A5: J2.15, U1.5 (A5)
/A6: J2.13, U1.4 (A6)
/A7: J2.11, U1.3 (A7)
/A8: J2.9, U1.25 (A8)
/A9: J2.7, U1.24 (A9)
/A10: J2.5, U1.21 (A10)
/A11: J2.3, U1.23 (A11)
/A12: J2.6, U1.2 (A12)
/A13: J2.8, U1.26 (A13)
/A14: J2.10, U1.1 (A14)
/A15: J2.12
/CLOCK: J2.4
/D0: J2.28, U1.11 (D0)
/D1: J2.26, U1.12 (D1)
/D2: J2.24, U1.13 (D2)
/D3: J2.22, U1.15 (D3)
/D4: J2.20, U1.16 (D4)
/D5: J2.18, U1.17 (D5)
/D6: J2.16, U1.18 (D6)
/D7: J2.14, U1.19 (D7)
/DMAB: J2.34
/IRQ3B: J2.29
/NMIB: J2.36
/PORT1CSB: J2.30, U1.20 (~CS)
/RAMCSB: J2.33
/RESET: J2.32
/RW: J2.27
GND: C1.2, J2.1, J2.31, U1.14 (GND), U1.22 (~OE)

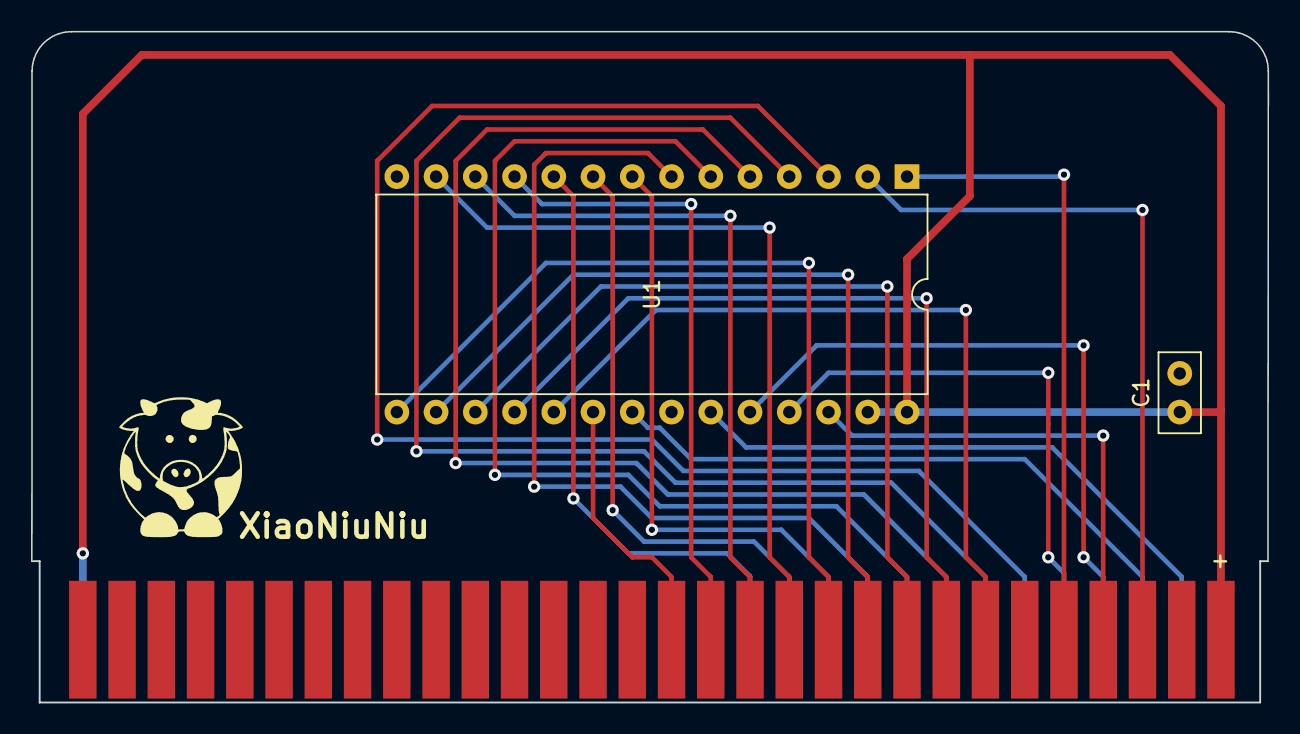
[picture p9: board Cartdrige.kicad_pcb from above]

Board: 2 copper layers, 80.0 x 43.4 mm, 4 parts (0 on the bottom side), 26 nets.

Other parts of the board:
XiaoNiuNiu: LOGO; VerySmallCow

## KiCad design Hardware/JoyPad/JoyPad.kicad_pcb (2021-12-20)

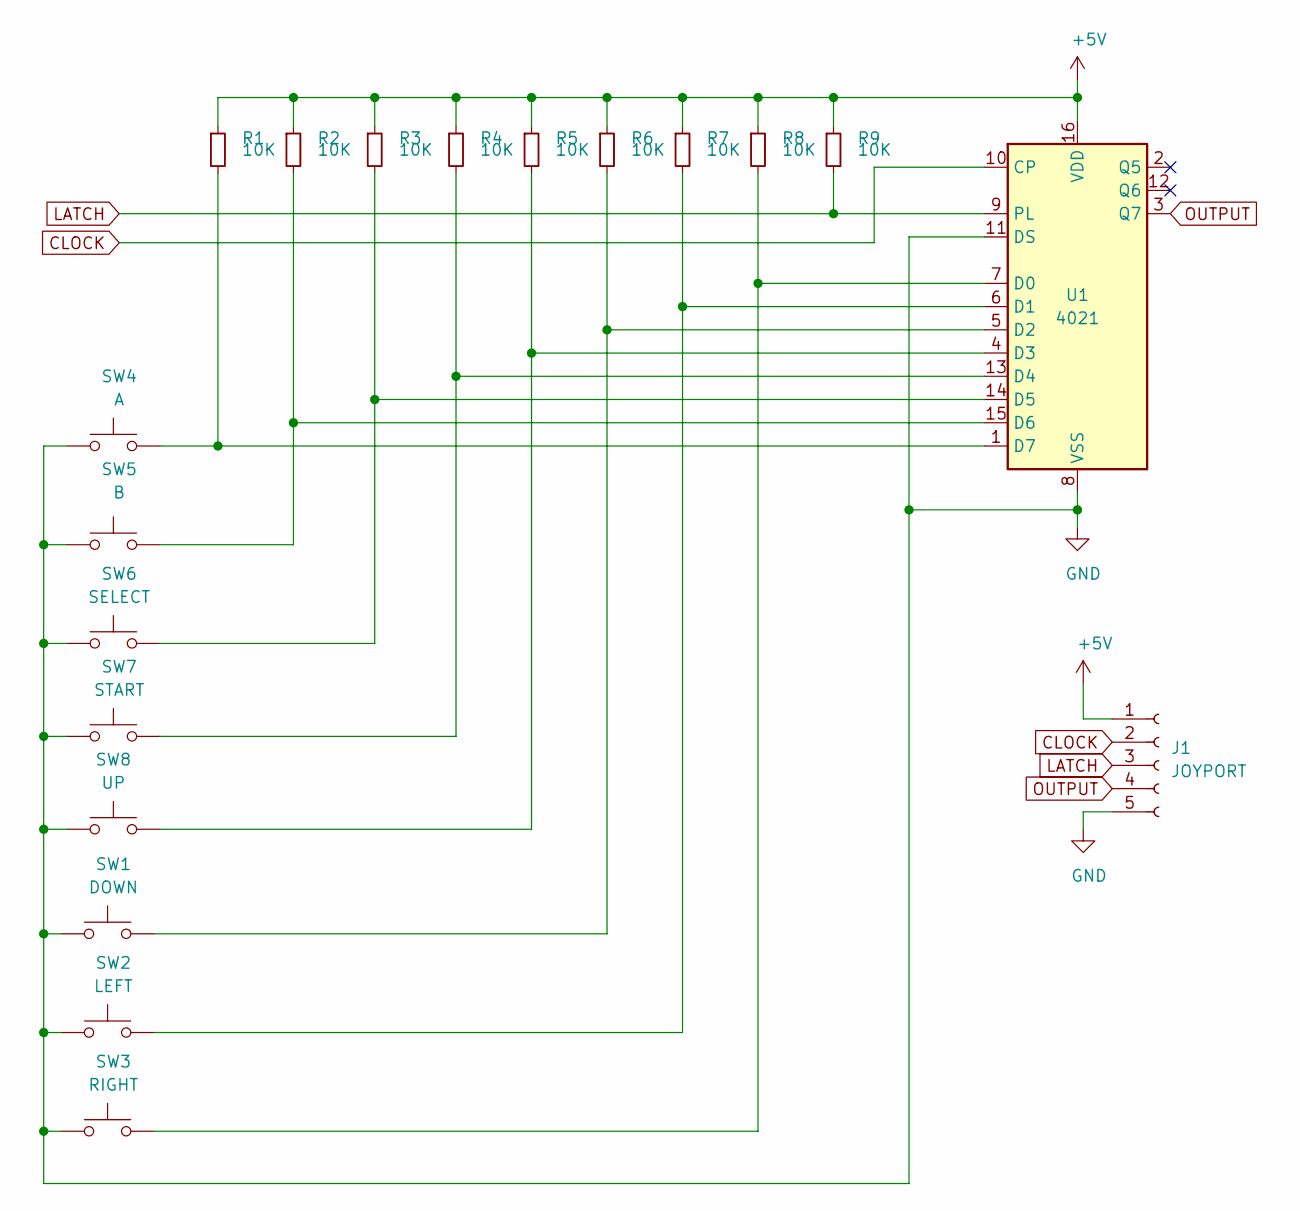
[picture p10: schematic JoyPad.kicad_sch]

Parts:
J1: JOYPORT; PinSocket_1x05_P2.54mm_Vertical
R1, R2, R3, R4, R5, R6, R7, R8, R9: 10K; R_Axial_DIN0207_L6.3mm_D2.5mm_P10.16mm_Horizontal
SW1: DOWN; SW_PUSH-12mm
SW2: LEFT; SW_PUSH-12mm
SW3: RIGHT; SW_PUSH-12mm
SW4: A; SW_PUSH-12mm
SW5: B; SW_PUSH-12mm
SW6: SELECT; SW_PUSH-12mm
SW7: START; SW_PUSH-12mm
SW8: UP; SW_PUSH-12mm
U1: 4021; DIP-16_W7.62mm

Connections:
+5V: J1.1, R1.1, R2.1, R3.1, R4.1, R5.1, R6.1, R7.1, R8.1, R9.1, U1.16 (VDD)
CLOCK: J1.2, U1.10 (CP)
GND: J1.5, SW1.1, SW2.1, SW3.1, SW4.1, SW5.1, SW6.1, SW7.1, SW8.1, U1.8 (VSS), U1.11 (DS)
LATCH: J1.3, R9.2, U1.9 (PL)
unnamed: R1.2, SW4.2, U1.1 (D7)
unnamed: R2.2, SW5.2, U1.15 (D6)
unnamed: R3.2, SW6.2, U1.14 (D5)
unnamed: R4.2, SW7.2, U1.13 (D4)
unnamed: R5.2, SW8.2, U1.4 (D3)
unnamed: R6.2, SW1.2, U1.5 (D2)
unnamed: R7.2, SW2.2, U1.6 (D1)
unnamed: R8.2, SW3.2, U1.7 (D0)
OUTPUT: J1.4, U1.3 (Q7)
no_connect_14: U1.12 (Q6)
no_connect_15: U1.2 (Q5)

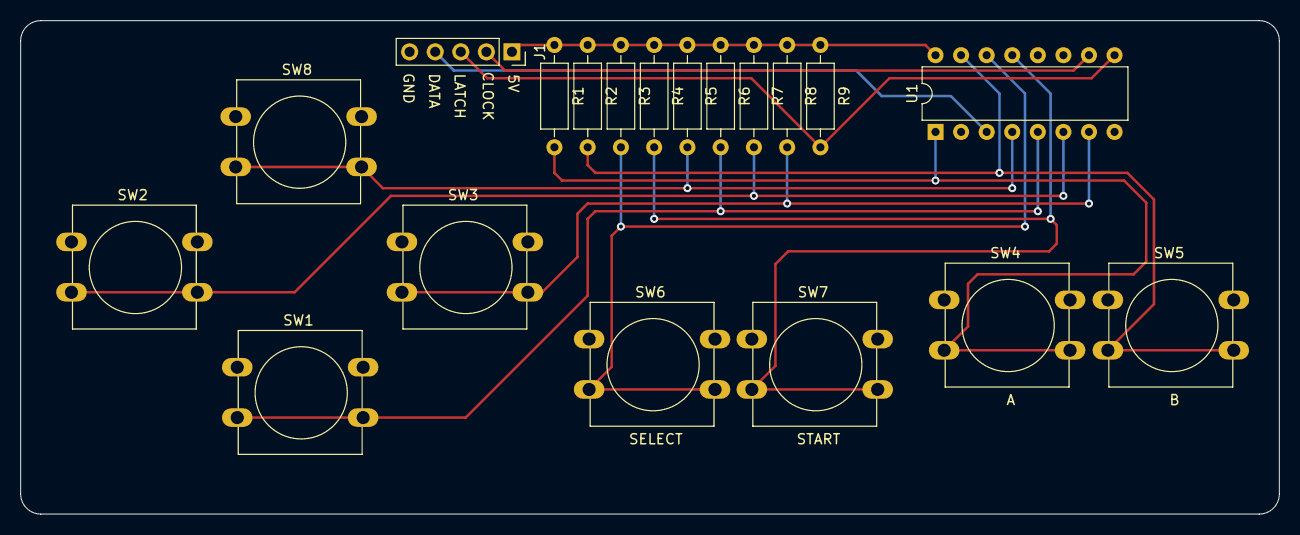
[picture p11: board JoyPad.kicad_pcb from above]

Board: 2 copper layers, 125.0 x 49.0 mm, 19 parts (0 on the bottom side), 13 nets.

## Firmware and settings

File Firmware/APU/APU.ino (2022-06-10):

#include "synth.h"

#define PIN_RW         (1 << PORTB1)
#define PIN_ENABLE     (1 << PORTB2)
#define PIN_CLOCK      (1 << PORTB4)
#define PIN_IRQ        (1 << PORTB5)

#define FUNC_CTRL      0x00
#define FUNC_STATUS    0x01
#define FUNC_SND0      0x10
#define FUNC_SND1      0x11
#define FUNC_SND2      0x12
#define FUNC_SND3      0x13

#define STATUS_READY   0b00000001

Synth synth;

word voice_data[] = {0, 0, 0, 0};
byte voice_mask[] = {0, 0, 0, 0};

word commands[256];
byte command_curr = 0;

byte status = 0;

void setup() {

  // Configure Control Port

  DDRB = ~(PIN_RW | PIN_ENABLE | PIN_CLOCK) | PIN_IRQ;

  // IRQ Disable

  PORTB |= PIN_IRQ;

  // Configure the Address and Data Bus

  DDRC = 0b00000000;
  DDRD = 0b11111111;
  PORTD = status;

  synth.begin();

  // Play a little note as diagnostic

  synth.setWave(0, TRIANGLE);
  synth.setEnvelope(0, ENVELOPE2, 3);
  synth.setSpeed(0, 16.0f);
  synth.setFrequency(0, 440.0f);
  synth.trigger(0);
  synth.wait();
  synth.setFrequency(0, 1000.0f);
  synth.trigger(0);
  synth.wait();

  synth.reset();

  cli();

  status |= STATUS_READY;

  for (;;) {

    // Check if a command is available, skip otherwise

    if (PINB & (PIN_ENABLE | PIN_CLOCK))
    {
      continue;
    }

    // Read the command

    const byte addr = PINC;
    const byte flags = PINB;

    if (flags & PIN_RW) {

      // Command is a read

      DDRD = 0b11111111;

      // Process the command

      switch (addr) {
        case FUNC_STATUS:
          PORTD = status;
          break;
      }

      while (!(PINB & PIN_ENABLE))
      {
        ; // wait to the end of the command
      }

      PORTB |= PIN_IRQ;
    } else {

      // Command is a write

      DDRD = 0b00000000;
      while (!(PINB & PIN_CLOCK))
      {
        ; // wait to receive the data
      }
      const byte data = PIND;

      while (!(PINB & PIN_ENABLE))
      {
        ; // wait to the end of the command
      }

      commands[command_curr++] = (addr << 8) + data;

      PORTB |= PIN_IRQ;

      if ((addr & 0x3F) == FUNC_CTRL) {

        // Execute the commands in the queue

        sei();
        process_commands();
        cli();

        // Notify CPU we are ready to accept next commands

        PORTB &= ~PIN_IRQ;
      }
    }
  }
}

void process_commands() {
  for (int i = 0; i < command_curr; i++) {

    // Parse the command

    const byte ctrl = (commands[i] >> 8) & 0x3F;
    const byte data = commands[i];

    // Execute the command

    switch (ctrl) {

      case FUNC_CTRL:
        for (int i = 0; i < 4; i++) if (voice_mask[i]) {
          const float pitch = (voice_data[i] >> 8) & 0x00FF;
          const byte wave   = (voice_data[i] >> 5) & 0x0007;
          const byte effect = (voice_data[i] >> 2) & 0x0007;
          const byte volume = (voice_data[i] >> 0) & 0x0003;
          const float speed = data;
          synth.setWave(i, wave);
          synth.setPitch(i, pitch);
          synth.setSpeed(i, speed);
          switch(effect) {
            case 1: // FADE_IN
              synth.setEnvelope(i, ENVELOPE1, volume);
              synth.setModulation(i, 64);
              break;
            case 2: // FADE OUT
              synth.setEnvelope(i, ENVELOPE2, volume);
              synth.setModulation(i, 64);
              break;
            case 3: // DROP
              synth.setEnvelope(i, ENVELOPE2, volume);
              synth.setModulation(i, 0);
              break;
            case 4: // SLIDE
              synth.setEnvelope(i, ENVELOPE0, volume);
              synth.setModulation(i, 127);
              break;
            case 5: // VIBRATO
              synth.setEnvelope(i, ENVELOPE3, volume);
              synth.setModulation(i, 64);
              break;
            default: // NONE
              synth.setEnvelope(i, ENVELOPE0, volume);
              synth.setModulation(i, 64);
              break;
          }
          synth.trigger(i);
        }
        synth.wait();
        for (int i = 0; i < 4; i++) {
          voice_data[i] = 0;
          voice_mask[i] = 0;
        }
        break;

      case FUNC_SND0:
        voice_data[0] = (voice_data[0] << 8) + data;
        voice_mask[0] = 1;
        break;
        
      case FUNC_SND1:
        voice_data[1] = (voice_data[1] << 8) + data;
        voice_mask[1] = 1;
        break;

      case FUNC_SND2:
        voice_data[2] = (voice_data[2] << 8) + data;
        voice_mask[2] = 1;
        break;
        
      case FUNC_SND3:
        voice_data[3] = (voice_data[3] << 8) + data;
        voice_mask[3] = 1;
        break;
    }
  }

  // Reset all commands

  command_curr = 0;
}

void loop() {
}

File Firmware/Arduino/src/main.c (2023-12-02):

#include "common.h"
#include "clock.h"
#include "piso.h"
#include "sipo.h"
#include "intr.h"
#include "nrf24.h"
#include "uart.h"
#include "util.h"
#include "proto.h"

#define MESSAGE "NRF24L01 Transmitter v1.0\r\n"
#define ADDRESS "00001"

uint16_t channels[CHANNELS];
packet_t packet;

int main(void)
{
    uart_init(115200);
    uart_set_stdout();
    printf(MESSAGE);
    clock_init();
    piso_init();
    sipo_init();
    intr_init();
    nrf24_init(ADDRESS);
    proto_init(channels);
    
    sei();

    while (1)
    {
        if (intr_is_interrupted())
        {
            const uint8_t val = piso_read();
            sipo_write(val);

            channels[0] = map(val, 0, 255, 1000, 2000);
            proto_encode_packet(channels, &packet);
            nrf24_write((const uint8_t *)&packet, sizeof(packet));

            printf("Processed 1 byte: %02X\r\n", val);
        }
    }

    return 0;
}

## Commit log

2020-11-21 Add buffers to extenstion ports
    [BusControl.kicad_sch, BusExtentions.kicad_sch, Main.kicad_sch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]
2020-11-22 Complete buffred extension ports
    [MotherBoard.kicad_pcb]
2020-12-05 Replace logic IC 4xxx by 74hcxx
    [Adapter-B_Cu.gbr, Adapter-B_Mask.gbr, Adapter-B_Paste.gbr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]
2020-12-25 Finalize daughter board
    [Adapter-B_Cu.gbr, Adapter-B_Mask.gbr, Adapter-B_Paste.gbr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]
2020-12-31 implement graphic loading from ROM
    [AdapterROM.kicad_pcb, AdapterROM.kicad_sch, Cartdrige.kicad_pcb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]
2021-01-01 Fix PPU dma loader
2021-01-02 Fix PPU
    [DaughterBoard.kicad_sch, VGACard.kicad_sch]
2021-01-03 Implement APU and fix schematics
    [BusControl.kicad_sch, BusExtentions.kicad_sch, DaughterBoard.kicad_pcb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]
2021-01-09 Implement DMA and PCB ports
    [BusControl.kicad_sch, BusExtentions.kicad_sch, DaughterBoard.kicad_pcb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]
2021-01-31 Version 1.2
    [AdapterCartdrige-B_Cu.gbr, AdapterCartdrige-B_Mask.gbr, AdapterCartdrige-B_Paste.gbr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]
2021-04-26 New PLD logic, VGA, DMA ...
    [AdapterCartdrigeDev.kicad_pcb, AdapterCartdrigeDev.kicad_sch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]
2021-12-20 Update to Kicad 6.0
    [DaughterBoard.kicad_pcb, DaughterBoard.kicad_sch, DaughterDevBoard.kicad_pcb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]
2021-12-21 Ignore Kicad backups
2022-05-03 New PPU - Direct Video Pixel
    [cu_top_0_pin_table.CSV, cu_top_0_sbt.sdf, cu_top_0_sbt_vital.sdf]
2022-05-09 Fix clock edge detection and refacter VGA signals
    [cu_top_0_pin_table.CSV, cu_top_0_sbt.sdf, cu_top_0_sbt_vital.sdf]
2022-05-10 Add DMA transfer
    [cu_top_0_pin_table.CSV, cu_top_0_sbt.sdf, cu_top_0_sbt_vital.sdf]
2022-05-21 Fix Reset, WAI Signal, Add PROG jumper and reformat luc files
    [DaughterDevBoard.kicad_pcb, DaughterDevBoard.kicad_sch, Main.kicad_sch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]
2022-05-21 Cleanup and update version
    [DaughterDevBoard.kicad_pcb, MotherBoard.kicad_pcb]
2022-05-21 Decouple ramdac and picture processing
    [cu_top_0_pin_table.CSV, cu_top_0_sbt.sdf, cu_top_0_sbt_vital.sdf]
2022-05-22 Add map management and scrolling
    [cu_top_0_pin_table.CSV, cu_top_0_sbt.sdf, cu_top_0_sbt_vital.sdf]
2022-05-28 Add OAM and Miniish editor
    [cu_top_0_pin_table.CSV, cu_top_0_sbt.sdf, cu_top_0_sbt_vital.sdf]
2022-05-28 Add sprite
    [cu_top_0_pin_table.CSV, cu_top_0_sbt.sdf, cu_top_0_sbt_vital.sdf]
2022-05-28 Better example with animation
    [cu_top_0_pin_table.CSV, cu_top_0_sbt.sdf, cu_top_0_sbt_vital.sdf]
2022-05-30 Increase to 64 sprites per frame
    [cu_top_0_pin_table.CSV, cu_top_0_sbt.sdf, cu_top_0_sbt_vital.sdf]
2022-05-31 Refactor, add ctrl and status, fix sprite at boundaries
    [cu_top_0_pin_table.CSV, cu_top_0_sbt.sdf, cu_top_0_sbt_vital.sdf]
2022-06-01 Add status read and map vram access
    [cu_top_0_pin_table.CSV, cu_top_0_sbt.sdf, cu_top_0_sbt_vital.sdf]
2022-06-07 Add monostable to reset PPU
    [DaughterDevBoard.kicad_sch, VGACard.kicad_sch]
2022-06-10 Add volume and fix enveloppes
    [APU.ino]
2022-06-17 Remove Alchitry shield
    [DaughterDevBoard.kicad_pcb, DaughterDevBoard.kicad_sch, VGACard.kicad_sch]
2023-05-06 New motherboard version
    [FrameBufferBoard.kicad_pcb, FrameBufferBoard.kicad_sch, Gpio.kicad_sch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]
2023-05-19 Finalize 1.3
    [Cartdrige-B_Cu.gbr, Cartdrige-B_Mask.gbr, Cartdrige-B_Paste.gbr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]
2023-05-31 Version 1.3
    [AdapterCartdrige-B_Cu.gbr, AdapterCartdrige-B_Mask.gbr, AdapterCartdrige-B_Paste.gbr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]
2023-06-04 Add SPI test
2023-06-05 Add SPI Board
    [MotherBoard.kicad_sch, NorthBridge.kicad_sch, SerialPeripheralInterfaceBoard.kicad_pcb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]
2023-07-15 A lot of new hardware
    [Cartdrige.kicad_pcb, Cartdrige.kicad_sch, CartdrigeDev.kicad_pcb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]
2023-07-16 Serial Software
    [KeyboardInterface.kicad_pcb, KeyboardInterface.kicad_sch]
2023-09-17 Better disk driver
2023-11-12 Add arduino firmware
2023-11-16 New hardware
    [ArduinoMultiInterface.kicad_pcb, ArduinoMultiInterface.kicad_sch]
2023-11-28 Add nfr24l01 protocol
    [ArduinoMultiInterface.kicad_pcb, ArduinoMultiInterface.kicad_sch]
2024-11-30 Add ArduinoMultiInterface
    [ArduinoMultiInterface-B_Cu.gbr, ArduinoMultiInterface-B_Mask.gbr, ArduinoMultiInterface-B_Paste.gbr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]
